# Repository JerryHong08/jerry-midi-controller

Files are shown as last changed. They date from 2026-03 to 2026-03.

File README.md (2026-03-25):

# MIDI Controller DIY Kits

> 归档一个从零到一的多通道 MIDI 控制器开源硬件项目

**项目文档**: [完整制作教程与技术分析](https://jerryhong08.github.io/)

---

## 产品概览

本项目提供两种规格的 MIDI 控制器套件，均采用模块化设计，支持 USB-MIDI 通信，兼容主流 DAW 软件（FL Studio, Ableton Live, Reaper, Resolume Arena 等）。

> **版本说明**：项目迭代过程中曾尝试 8路电动推子版、15路VJ版等原型，因当时经验不足且精力有限，相关文档与代码未完整归档。目前**仅 4通道电动推子版**和**16路旋转编码器版**完整整理出全部需要文件。

### 4 通道电动推子版

适合音频混音、VJ 演出控制

| 规格 | 参数 |
|---|---|
| 电动推子 | 4 路，带触摸感应 |
| 旋转编码器 | 4 路，无极旋转 |
| RGB 按钮 | 4 个 |
| 分页功能 | 支持 4 组页面切换（共 64 CC 通道） |
| 主控芯片 | ESP32-S3 |
| 通信协议 | USB-MIDI + I2C |

**架构特点**：
- 主控 ESP32-S3 负责 USB-MIDI 通信
- 专用推子从板（Arduino Nano）处理 PID 电机控制
- 编码器从板（ESP32-S2）处理旋转输入
- I2C 总线连接，可扩展至 15+ 通道

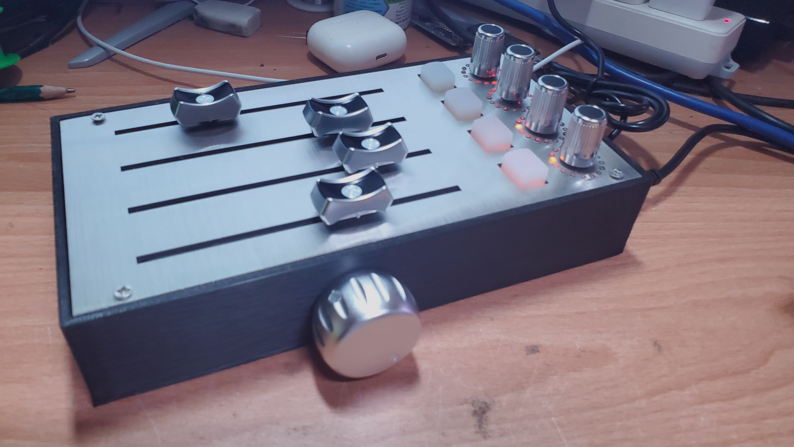
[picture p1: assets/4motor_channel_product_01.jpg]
4路电动推子版实物
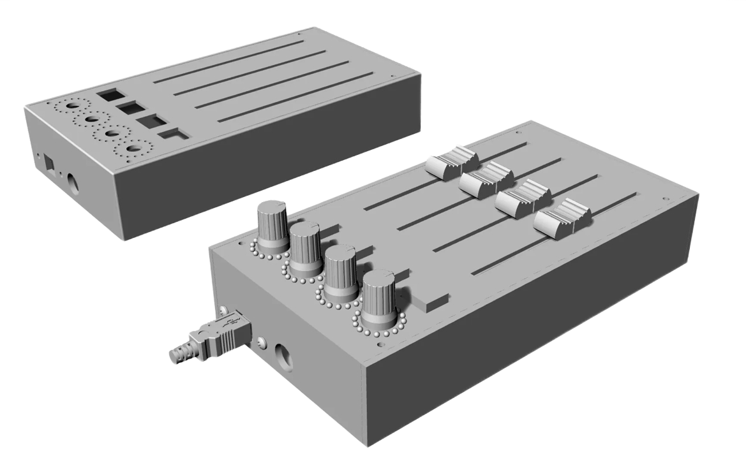
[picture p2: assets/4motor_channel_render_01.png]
4路电动推子版渲染图
 

### 16 路旋转编码器版

适合参数精细化调节、灯光控制

| 规格 | 参数 |
|---|---|
| 旋转编码器 | 16 路，带按压功能 |
| LED 环形指示灯 | 256 颗（每编码器 16 颗） |
| 分页功能 | 支持 8 组页面切换（共 128 CC 通道） |
| 主控芯片 | ESP32-S3 |
| LED 驱动 | MAX7219 × 4 |
| 通信协议 | USB-MIDI + I2C |

**架构特点**：
- 双板设计：S3 主控 + S2 编码器处理板
- MCP23017 × 2 扩展 32 路 GPIO
- 4 片 MAX7219 级联驱动 256 颗 LED

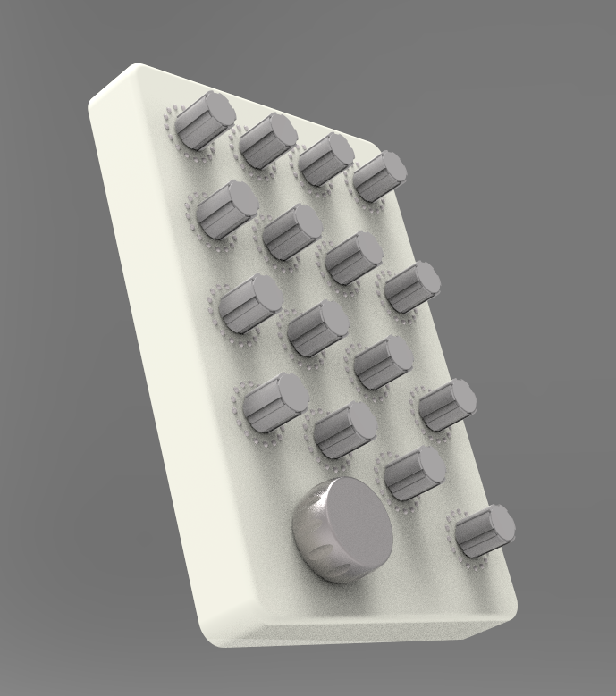
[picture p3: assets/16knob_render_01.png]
16旋转编码器版渲染图
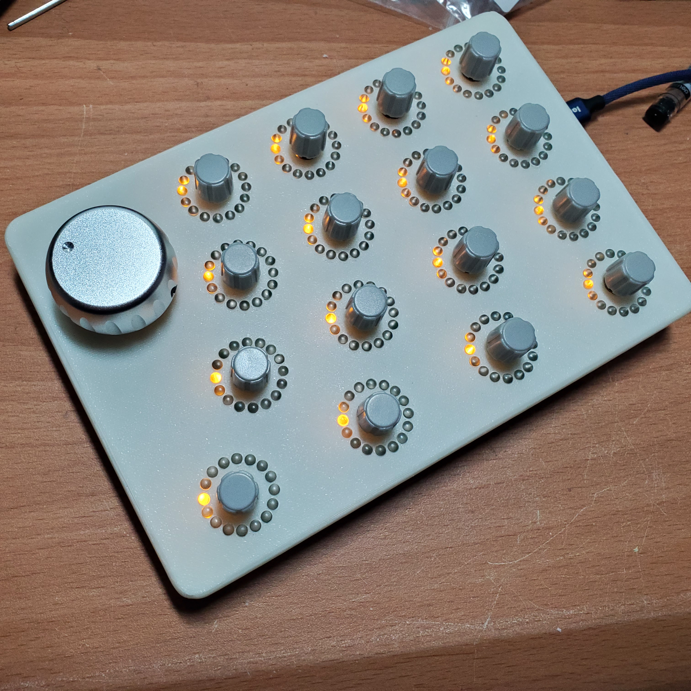
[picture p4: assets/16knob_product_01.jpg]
16旋转编码器版实物
 

---

## 快速开始

### 文件结构

```
release/
├── 4_channel/           # 4通道电动推子套件
│   ├── 3d/              # 外壳 3D 模型 (.step)
│   ├── pcb/             # 电路板 Gerber 文件
│   ├── code/            # 固件代码
│   │   ├── esp32s3_standard_4pages.ino    # 主控代码
│   │   ├── Motor-Controller/              # 推子从板代码
│   │   └── 4encoder_ESP32S2/              # 编码器从板代码
│   └── 物料单.csv        # BOM 清单
│
└── 16encoder/           # 16路旋转编码器套件
    ├── 3d/              # 外壳 3D 模型
    ├── pcb/             # 电路板 Gerber 文件
    ├── code/            # 固件代码
    │   ├── 16encoder/                   # S3 主控代码
    │   └── 16encoder_ESP32S2/           # S2 编码器板代码
    └── 物料单.csv        # BOM 清单
```

### 制作流程概览

1. **下载物料**：根据 `物料单.csv` 采购元件
2. **PCB 打样**：将 `pcb/` 文件夹中的文件提交至嘉立创等平台
3. **3D 打印**：使用 `3d/` 中的 `.step` 文件打印外壳
4. **焊接组装**：按教程焊接 PCB（推荐顺序：LED → 芯片 → 主控）
5. **烧录固件**：分别上传主控和从板代码
6. **测试使用**：连接电脑，在 DAW 中配置 MIDI 映射

---

## 技术亮点

### 电动推子实现

- **PID 控制算法**：实时精准定位，消除 overshoot
- **电容触摸感应**：检测人手接触，避免电机与用户对抗
- **双向 MIDI 通信**：DAW 参数变化实时同步到物理推子位置

### 旋转编码器实现

- **速度自适应**：快速旋转时自动增加步进值
- **LED 位置指示**：16 颗 LED 组成环形，直观显示当前值
- **零延迟反馈**：I2C 从板专门处理编码器中断，主控零负担

---

## 硬件架构图

### 4 通道版本硬件架构

```mermaid
flowchart TB
    subgraph PC["电脑端"]
        DAW[DAW软件<br/>FL Studio/Resolume等]
    end

    subgraph MainBoard["主控板 (ESP32-S3)"]
        USB[(USB-MIDI接口)]
        I2CMaster[I2C Master控制器]
        MCU[MCU协议处理器]
        PageEnc[分页编码器]
        RGBCtrl[WS2812B灯带控制器]
    end

    subgraph FaderBoard["电动推子从板 (Arduino Nano x4)"]
        I2CSlave8[I2C Slave @ 0x08]
        PID1[PID控制器×4]
        Motor[电机驱动×4]
        Touch[电容感应×4]
        ADC[位置传感器×4]
    end

    subgraph EncoderBoard["编码器从板 (ESP32-S2)"]
        I2CSlave9[I2C Slave @ 0x09]
        MCP23017_1[MCP23017 @ 0x20]
        ENC[旋转编码器×4]
    end

    subgraph Buttons["按钮与显示"]
        Mux[CD74HC4067<br/>多路复用器]
        RGBBtn[RGB按钮×4]
        NoteBtn[音符按钮×16]
    end

    DAW <-->|USB-MIDI| USB
    USB <-->|双向MIDI数据| MCU
    MCU <-->|控制指令| I2CMaster
    I2CMaster <-->|I2C总线| I2CSlave8
    I2CMaster <-->|I2C总线| I2CSlave9

    I2CSlave8 <-->|目标位置| PID1
    PID1 -->|PWM信号| Motor
    Touch -->|触摸状态| I2CSlave8
    ADC -->|当前位置| PID1

    I2CSlave9 <-->|GPIO扩展| MCP23017_1
    MCP23017_1 <-->|AB相输入| ENC

    MCU <-->|读取| Mux
    Mux <-->|扫描| NoteBtn
    MCU <-->|单线控制| RGBBtn
    MCU <-->|中断输入| PageEnc
```

### 16 旋转编码器版本架构

```mermaid
flowchart TB
    subgraph PC16["电脑端"]
        DAW16[DAW软件]
    end

    subgraph Main16["主控板 (ESP32-S3)"]
        USB16[(USB-MIDI)]
        I2C16[I2C Master]
        MAX7219[MAX7219×4<br/>LED矩阵驱动]
        Mux16[CD74HC4067<br/>按钮多路复用]
        PageEnc16[分页编码器]
    end

    subgraph Encoder16["编码器从板 (ESP32-S2)"]
        I2C16Slave[I2C Slave @ 0x09]
        MCP1[MCP23017 @ 0x20<br/>编码器0-7]
        MCP2[MCP23017 @ 0x21<br/>编码器8-15]
        ENC16[EC11旋转编码器×16]
        LED16[LED环形指示灯×256]
    end

    DAW16 <-->|USB-MIDI| USB16
    USB16 <-->|双向数据| I2C16
    I2C16 <-->|读取编码器值| I2C16Slave
    I2C16 <-->|更新LED显示| MAX7219
    MAX7219 -->|SPI| LED16

    I2C16Slave <-->|I2C| MCP1
    I2C16Slave <-->|I2C| MCP2
    MCP1 <-->|A/B相| ENC16
    MCP2 <-->|A/B相| ENC16

    I2C16 <-->|读取按钮| Mux16
    I2C16 <-->|分页控制| PageEnc16
```
---

*本项目为个人学习与作品展示用途，不提供售后支持。DIY 有风险，焊接需谨慎。*

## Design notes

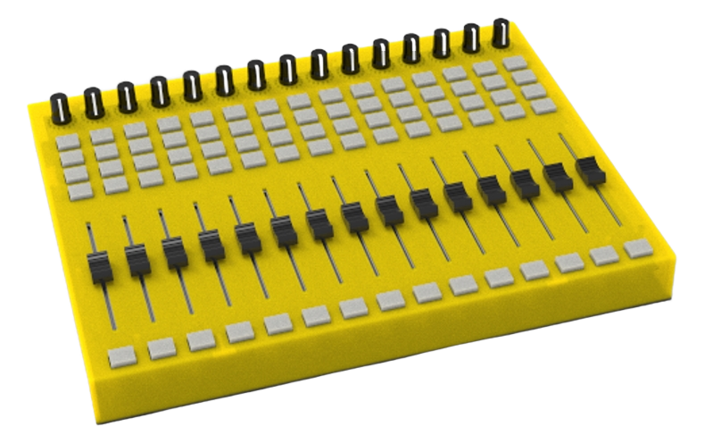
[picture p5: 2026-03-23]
assets/15VJ_render_01.png

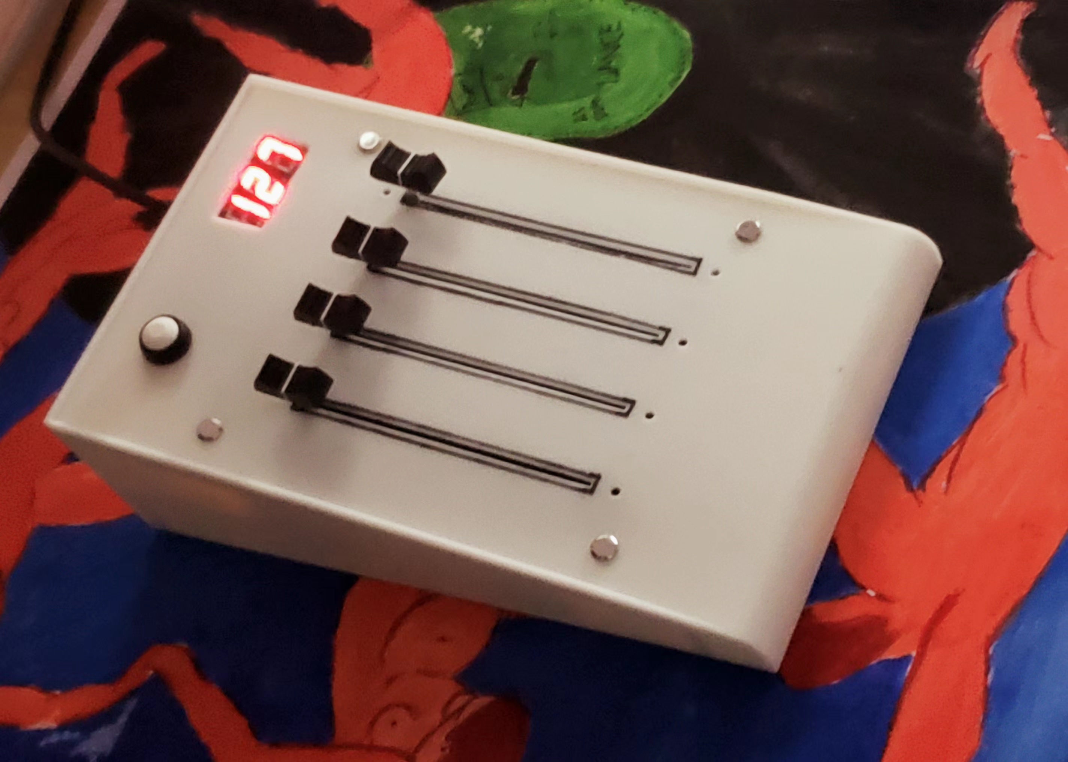
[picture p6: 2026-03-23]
assets/4channel_product_02.jpg

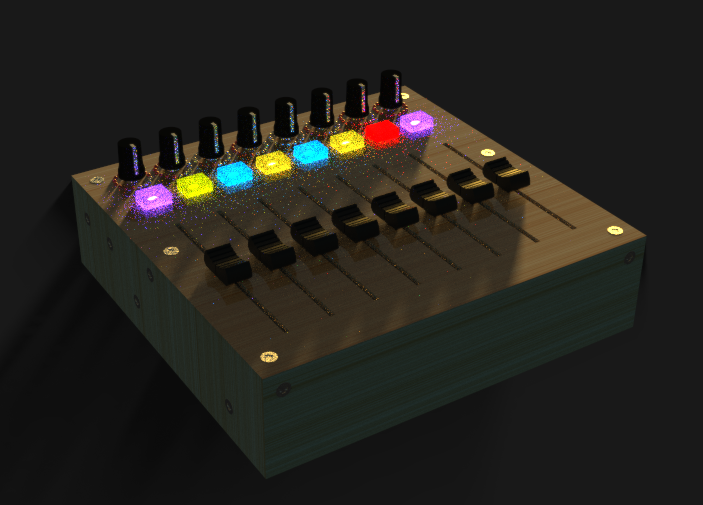
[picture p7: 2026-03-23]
assets/8motor_channel_render_01.png

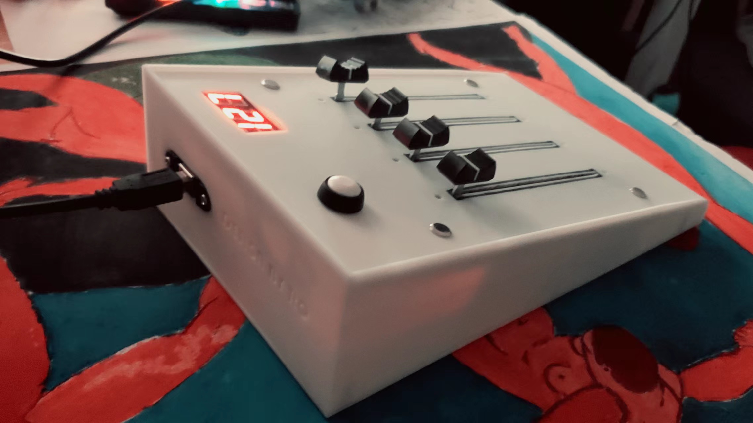
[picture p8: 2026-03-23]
assets/4channel_product_01.jpg

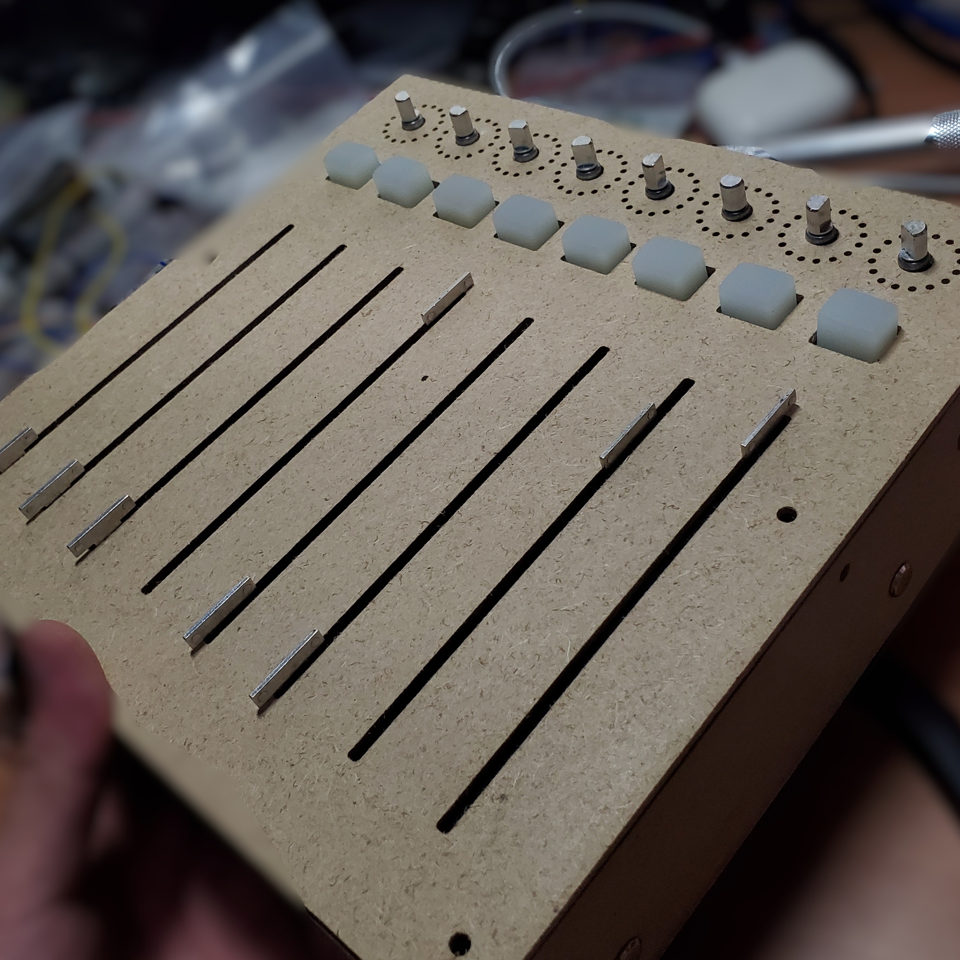
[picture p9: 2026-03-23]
assets/8motor_channel_product_02.jpg

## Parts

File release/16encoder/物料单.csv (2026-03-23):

名称 | 购买链接 | 所属类别 | 数量 | 单价 | 总额 | 描述 | 型号
4067 | https://detail.tmall.com/item.htm?_u=f202183fbd71d4&id=692645144312&spm=a1z09.2.0.0.53802e8dpcbRg8 | IC, 子板元件 | 1 | 1.37 | 1.37 | 16个按钮的i/o拓展ic | CD74HC4067M96 SOIC-24
mcp23017 | https://item.taobao.com/item.htm?_u=f202183fbd3312&id=755560235410&spm=a1z09.2.0.0.53802e8dpcbRg8 | IC, 子板元件 | 2 | 5.1 | 10.2 | 8个encoder的拓展ic | MCP23017-E/SO 贴片 SOP-28
max7219 | https://item.taobao.com/item.htm?_u=f202183fbd1c23&id=615828078210&skuId=4900726339770 | IC, 子板元件 | 4 | 1.1 | 4.4 | 4个16led的ec11灯环 | MAX7219CWG SOP24
电容电阻等 |  | PCB小元件, 主板元件, 子板元件 |  |  | 0 | 100nf 10uf 10k贴片电阻
10k贴片电阻 | https://item.taobao.com/item.htm?spm=a1z09.2.0.0.53802e8dpcbRg8&id=739043743825&_u=f202183fbdcd3e | PCB小元件, 主板元件, 子板元件 | 40 | 0.15 | 6 | 侧边ec11、子板ec11旋钮的AB引脚上拉电阻 | 10K （一件100只）精度：1%精度阻值：0805贴片电阻
0.1uf贴片电容 | https://detail.tmall.com/item.htm?_u=f202183fbdccdb&id=744920698405&spm=a1z09.2.0.0.53802e8dpcbRg8 | PCB小元件, 子板元件 | 7 | 0.03 | 0.21 | max7219、rgbled滤波 | 0805 100NF 0.1UF 10% 25V 50个
10uf贴片电容 | https://detail.tmall.com/item.htm?_u=f202183fbd6e30&id=19327803085&spm=a1z09.2.0.0.53802e8dpcbRg8 | PCB小元件, 子板元件 | 4 | 0.256 | 1.024 | max7219滤波 | 25V 10UF 体积4*5.4mm
EC11 | https://item.taobao.com/item.htm?_u=f202183fbdef1d&id=770659040644&spm=a1z09.2.0.0.53802e8dpcbRg8 | 子板元件 | 17 | 1.5 | 25.5 | 旋钮 | 插件-薄型半圆D柄15长[带开关]脉冲定位：15脉冲30定位
ESP32S3 | https://item.taobao.com/item.htm?spm=a1z09.2.0.0.53802e8dpcbRg8&id=718248966902&_u=f202183fbd6cbc | 主板元件, 单片机 | 1 | 27 | 27 | 主芯片 | ESP32-S3-N16R8（Type-c接口 已焊排针）
ESP32S2 | https://item.taobao.com/item.htm?spm=a1z09.2.0.0.53802e8dpcbRg8&id=620692837143&_u=f202183fbd0ad7 | 主板元件, 单片机 | 1 | 22.73 | 22.73 | 负责处理mcp连接的ec11并与主芯片ESP32S3 i2c通讯 | ESP-32开发板已焊接（CP2102）
led导光柱 |  | 配件 | 256 | 0.23 | 58.88
EC11帽 | https://item.taobao.com/item.htm?spm=a1z09.2.0.0.53802e8dpcbRg8&id=709758245843&_u=f202183fbd8e55 | 配件 | 16 | 0.5 | 8 | 11.3X11mm灰色 D型半轴 | 11.3X11mm灰色 D型半轴
侧边旋钮帽 | https://item.taobao.com/item.htm?_u=e202183fbd0adb&id=566707705482&spm=a1z09.2.0.0.4a612e8dyv1X5v | 配件 | 1 | 11.21 | 11.21 | 侧边翻页旋钮帽 | 圆鼓型银色35x20x6小圆标
3d打印外壳 | https://item.taobao.com/item.htm?spm=a1z09.2.0.0.53802e8dpcbRg8&id=740929972228&_u=f202183fbdbb9a | 外壳面板 | 1 | 43 | 43 | 黑色 ABS 淘宝下单 | ABS 黑色
主板pcb | 嘉立创 | PCB | 1 | 13 | 13 | 主板 | 16encoder
type c线 |  | 线材 | 1 | 1.1 | 1.1 | type c数据线 | type c
固定螺丝 |  | 零件 |  |  | 0
M2*5螺丝 | https://detail.1688.com/offer/710364219126.html?spm=a360q.8274423.0.0.76354c9atedfFn | 零件 | 12 | 0.02 | 0.24 | 底面4个自攻螺丝 | 304不锈钢十字平头螺丝KM沉头机螺钉M3*5

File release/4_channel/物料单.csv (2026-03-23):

名称 | 购买链接 | 单价 | 所属类别 | 数量 | 总额 | 描述 | 型号
4067 | https://detail.tmall.com/item.htm?_u=f202183fbd71d4&id=692645144312&spm=a1z09.2.0.0.53802e8dpcbRg8 | 1.37 | IC, 子板元件 | 1 | 1.37 | 16个按钮的i/o拓展ic | CD74HC4067M96 SOIC-24
mcp23017 | https://item.taobao.com/item.htm?_u=f202183fbd3312&id=755560235410&spm=a1z09.2.0.0.53802e8dpcbRg8 | 5.1 | IC, 子板元件 | 1 | 5.1 | 8个encoder的拓展ic | MCP23017-E/SO 贴片 SOP-28
max7219 | https://item.taobao.com/item.htm?_u=f202183fbd1c23&id=615828078210&skuId=4900726339770 | 1.1 | IC, 子板元件 | 1 | 1.1 | 4个16led的ec11灯环 | MAX7219CWG SOP24
tb6612fng | https://item.taobao.com/item.htm?_u=f202183fbde8af&id=607254624071&skuId=5205675671358 | 7 | 主板元件, 元件模块 | 2 | 14 | 电动推子驱动ic | TB6612FNG
FFC/FPC连接件 | https://detail.tmall.com/item.htm?_u=f202183fbda82a&id=626563665786&spm=a1z09.2.0.0.53802e8dpcbRg8 | 0.2 | 主板元件, 子板元件 | 2 | 0.4 | 子主板连接部件 | FFC/FPC 1.0mm-14P-翻盖下接
ws2812_RGBLED | https://item.taobao.com/item.htm?_u=f202183fbdb778&id=733895338208&spm=a1z09.2.0.0.53802e8dpcbRg8 | 0.08 | 子板元件 | 4 | 0.32 | rgbled | ws2812b_1210
电容电阻等 |  |  | PCB小元件, 主板元件, 子板元件 |  | 0 | 4MΩ 100nf 10uf 10k贴片电阻
10k贴片电阻 | https://item.taobao.com/item.htm?spm=a1z09.2.0.0.53802e8dpcbRg8&id=739043743825&_u=f202183fbdcd3e | 0.15 | PCB小元件, 主板元件, 子板元件 | 13 | 1.95 | 侧边ec11、子板ec11旋钮的AB引脚上拉电阻 | 10K （一件100只）精度：1%精度阻值：0805贴片电阻
0.1uf贴片电容 | https://detail.tmall.com/item.htm?_u=f202183fbdccdb&id=744920698405&spm=a1z09.2.0.0.53802e8dpcbRg8 | 0.03 | PCB小元件, 子板元件 | 5 | 0.15 | max7219、rgbled滤波 | 0805 100NF 0.1UF 10% 25V 50个
10uf贴片电容 | https://detail.tmall.com/item.htm?_u=f202183fbd6e30&id=19327803085&spm=a1z09.2.0.0.53802e8dpcbRg8 | 0.256 | PCB小元件, 子板元件 | 1 | 0.256 | max7219滤波 | 25V 10UF 体积4*5.4mm
400uf电解电容 | https://item.taobao.com/item.htm?spm=a1z09.2.0.0.53802e8dpcbRg8&id=611726699981&_u=f202183fbd1568 | 0.129 | PCB小元件, 主板元件 | 2 | 0.258 | 电动推子读值滤波 | 直插25V 470UF 体积8X12
4.3MΩdip电阻 | https://item.taobao.com/item.htm?_u=f202183fbd3981&id=657636293268&spm=a1z09.2.0.0.53802e8dpcbRg8 | 0.029 | PCB小元件, 主板元件 | 4 | 0.116 | 电动推子电容感应电路电阻 | 4.3M数量：1/4W 1%（100只）
0.1ufdip电容 | https://item.taobao.com/item.htm?_u=f202183fbdc7b7&id=560981290395&spm=a1z09.2.0.0.53802e8dpcbRg8 | 0.03 | PCB小元件, 主板元件 | 7 | 0.21 | 电动推子模拟输入口滤波 | 瓷片电容 104 0.1uF 100NF 50V
电动推子 | https://item.taobao.com/item.htm?_u=f202183fbd6603&id=565414327389&skuId=5187797482224 | 35 | 主板元件 | 4 | 140 | 电动推子 | 日本推子雅马哈m7clls9电位器RSA0N11M9A0J
EC11 | https://item.taobao.com/item.htm?_u=f202183fbdef1d&id=770659040644&spm=a1z09.2.0.0.53802e8dpcbRg8 | 1.5 | 子板元件 | 4 | 6 | 旋钮 | 插件-薄型半圆D柄15长[带开关]脉冲定位：15脉冲30定位
侧边EC11 | https://item.taobao.com/item.htm?spm=a1z09.2.0.0.53802e8dpcbRg8&id=655360561536&_u=f202183fbd7c99 | 2.3 | 主板元件 | 1 | 2.3 | 侧边翻页旋钮 | 柄长=20mm轴型：半圆轴脉冲定位：15脉冲30位正向
3vto5v | https://detail.tmall.com/item.htm?_u=s202183fbd09cc&id=674616282888&spm=a1z09.2.0.0.f05f2e8d9XiBlQ | 8.55 | 主板元件 | 1 | 8.55 | 电压转化 | 无针0.7-5V转5V
ESP32S3 | https://item.taobao.com/item.htm?spm=a1z09.2.0.0.53802e8dpcbRg8&id=718248966902&_u=f202183fbd6cbc | 27 | 主板元件, 单片机 | 1 | 27 | 主芯片 | ESP32-S3-N16R8（Type-c接口 已焊排针）
ESP32S2 | https://item.taobao.com/item.htm?spm=a1z09.2.0.0.53802e8dpcbRg8&id=620692837143&_u=f202183fbd0ad7 | 22.73 | 主板元件, 单片机 | 1 | 22.73 | 负责处理mcp连接的ec11并与主芯片ESP32S3 i2c通讯 | ESP-32开发板已焊接（CP2102）
arduino nano | https://item.taobao.com/item.htm?spm=a1z09.2.0.0.53802e8dpcbRg8&id=646953465886&_u=f202183fbd0be2 | 11.4 | 主板元件, 单片机 | 1 | 11.4 | 负责处理电动推子 | nano V3.0 Atmega328P开发板
led导光柱 | https://trade.1688.com/order/buyer_order_list.htm?_input_charset=utf-8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 | 0.23 | 配件 | 64 | 14.72 | LDT2.0导光柱2mm板孔透光柱 草帽灯导光柱 | LDT2.0-9.5
硅胶按钮 | https://item.taobao.com/item.htm?_u=f202183fbd39aa&id=601951354876&skuId=5065731458263 | 1.5 | 配件 | 4 | 6 | 硅胶导电按钮，需要注意导电片的清洁 | 导电胶电子开关橡胶按键帽现货HJ60
电动推子导电帽 | https://item.taobao.com/item.htm?spm=a1z09.2.0.0.53802e8dpcbRg8&id=568927718232&_u=f202183fbdf6e3 | 9 | 配件 | 4 | 36 | 导电推子帽 | MA2控台2色选
EC11帽 | https://item.taobao.com/item.htm?spm=a1z09.2.0.0.53802e8dpcbRg8&id=709758245843&_u=f202183fbd8e55 | 0.5 | 配件 | 8 | 4 | 12X18mm黑色[D型半轴]旋钮帽 | 12X18mm黑色[D型半轴]
侧边旋钮帽 | https://item.taobao.com/item.htm?_u=e202183fbd0adb&id=566707705482&spm=a1z09.2.0.0.4a612e8dyv1X5v | 11.21 | 配件 | 1 | 11.21 | 侧边翻页旋钮帽 | 圆鼓型银色35x20x6小圆标
3d打印外壳 | https://item.taobao.com/item.htm?spm=a1z09.2.0.0.53802e8dpcbRg8&id=740929972228&_u=f202183fbdbb9a | 30 | 外壳面板 | 1 | 30 | 黑色 ABS 淘宝下单 | ABS 黑色
面板定制铝合金顶面板 | https://item.taobao.com/item.htm?spm=a1z09.2.0.0.53802e8dpcbRg8&id=610352053418&_u=f202183fbd9fca | 10 | 外壳面板 | 1 | 10 | 2mm 淘宝大批量下单 | 铝合金面板定制
主板pcb | 嘉立创 | 2 | PCB | 1 | 2 | 主板 | 4fader_main_v2
子板pcb | 嘉立创 | 2 | PCB | 1 | 2 | 子板 | 4fader_Sub_v2
FFC/FPC线 | https://item.taobao.com/item.htm?spm=a1z09.2.0.0.53802e8dTWQTVr&id=555563074622&_u=f202183fbdc1af | 3 | 线材 | 1 | 3 | 200mm 15p 0.5mm | 14Pin（10条）间距：1．0mm方向：反向/B型长度：10厘米（100mm）
USBC公转USBB母线 | https://item.taobao.com/item.htm?spm=a1z09.2.0.0.53802e8dTWQTVr&id=717578689881&_u=f202183fbd1eae | 5 | 线材 | 1 | 5 | 连接ESP32S3 OTG usbc接口转至usbb | 打印母USB2.0转Type-c公头连接线 打印方口B母带螺丝可固定数据线
USBB线 | https://detail.1688.com/offer/841248184260.html?cosite=-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 | 1.1 | 线材 | 1 | 1.1 | usbb连接电脑midi线 | 黑色方口铜芯打印机连接线 USB2.0打印线扫描仪1.2米
9VDC线 | https://detail.1688.com/offer/751129188813.html?spm=a360q.8274423.0.0.76354c9atedfFn | 5 | 线材 | 1 | 5 | 9V电动推子供电电源线 | 适配器9V1A DC5.5*2.5/2.1【388壳】
固定螺丝 |  |  | 零件 |  | 0
M3*26 | https://detail.1688.com/offer/706866952813.html?spm=a360q.8274423.0.0.76354c9atedfFn | 0.23 | 零件 | 2 | 0.46 | 主板双通螺栓支柱2个 | M3*26
M3*9 | https://detail.1688.com/offer/706866952813.html?spm=a360q.8274423.0.0.76354c9atedfFn | 0.08 | 零件 | 2 | 0.16 | 子板双通螺栓支柱2个 | M3*9
M3*7+6 | https://detail.1688.com/offer/707751582992.html?spm=a360q.8274423.0.0.76354c9atedfFn | 0.1 | 零件 | 4 | 0.4 | 主板单头螺栓柱4个 | M3*7+6
M3*24+4 | https://detail.1688.com/offer/707751582992.html?spm=a360q.8274423.0.0.76354c9atedfFn | 0.26 | 零件 | 4 | 1.04 | 子板单头螺栓柱4个 | M3*24+4
M3螺母 | https://detail.1688.com/offer/708874590991.html?spm=a360q.8274423.0.0.76354c9atedfFn | 0.03 | 零件 | 4 | 0.12 | 子主板螺母各2共4个 | 304不锈钢螺帽六角薄螺母锁紧螺丝帽M3
M3*5螺丝 | https://detail.1688.com/offer/710364219126.html?spm=a360q.8274423.0.0.76354c9atedfFn | 0.02 | 零件 | 12 | 0.24 | 底面8顶面4共12个螺丝 | 304不锈钢十字平头螺丝KM沉头机螺钉M3*5

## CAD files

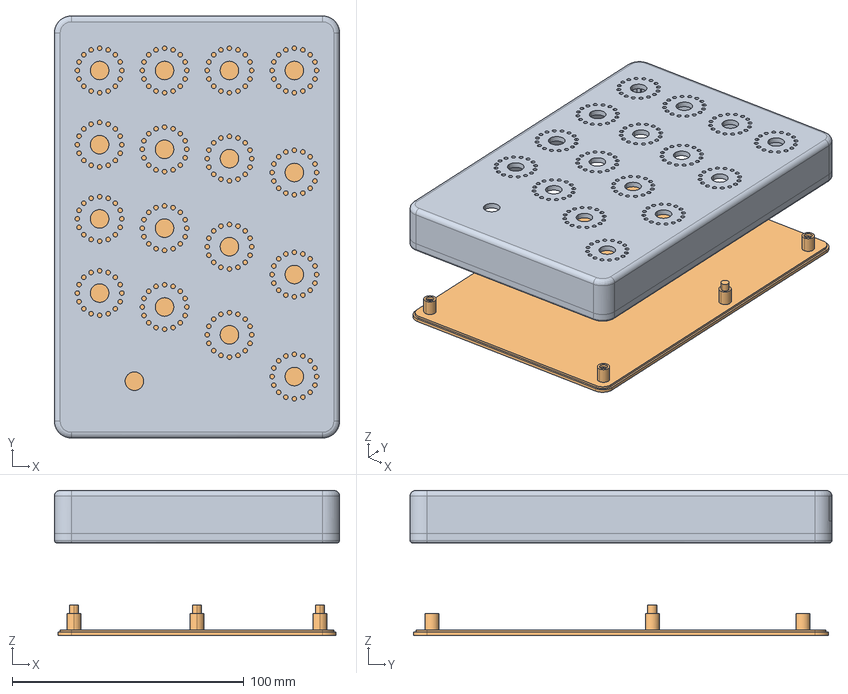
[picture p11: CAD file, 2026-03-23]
release/16encoder/3d/16encoder_3DShell.stp
123.0 x 182.0 x 62.6 mm

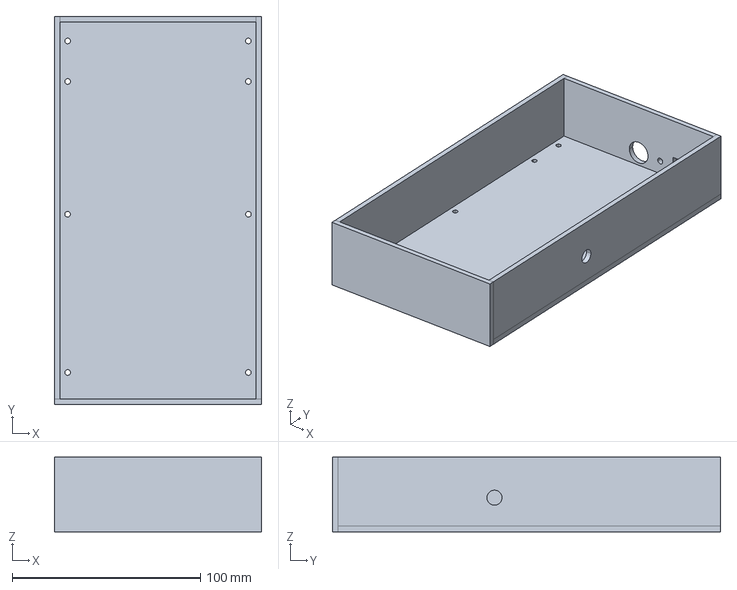
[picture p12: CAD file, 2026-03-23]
release/4_channel/3d/4_channel.stp
110.0 x 206.0 x 39.6 mm
